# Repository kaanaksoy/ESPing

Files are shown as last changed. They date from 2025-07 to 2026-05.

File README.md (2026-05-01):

# ESPing – A Wi-Fi Button That Sleeps

**ESPing** is a battery-friendly ESP32-C6 project that acts as a stateless smart button.  
On wake, it connects to Wi-Fi, fires an MQTT event, and goes straight back to deep sleep — typically in under a second on subsequent presses.

---

## ✨ Features

- Fast wake → Wi-Fi → MQTT → sleep (~400–800 ms after the first connect)
- WiFi fast-reconnect via cached BSSID/channel/IP in RTC memory (no router config needed)
- Ultra-low-power operation (ideal for 18650 battery)
- MQTT with Home Assistant auto-discovery — appears as a native HA device with button triggers, battery sensor, and config switch
- `pressed` / `released` device-trigger events, with `retain=false` so HA doesn't replay stale presses on reconnect
- Last Will & Testament so HA correctly marks the device offline if it dies mid-session
- `preventSleep` mode for OTA flashing and live config tweaks
- Color-configurable status NeoPixel (settable from HA via MQTT)
- Battery percentage reported on every press
- **Per-board unique ID derived from chip MAC** — flash the same firmware to every unit, no per-device editing

---

## 📦 MQTT Topics

All topics are prefixed with the runtime device ID, e.g. `esping-a1b2c3d4e5f6/`.

| Topic | Direction | Description |
|---|---|---|
| `<id>/button` | publish | `pressed` then `released` on each wake (not retained) |
| `<id>/battery` | publish | JSON `{"batteryPercentage": 87.4}` (retained) |
| `<id>/state` | publish | JSON state: `preventSleep`, color, brightness (retained) |
| `<id>/availability` | publish | `online` / `offline` via LWT (retained) |
| `<id>/command` | subscribe | JSON commands — see below |
| `homeassistant/+/<id>_*/config`| publish | HA discovery payloads (retained, version-gated) |

### Command payloads

Send JSON to `<id>/command`:

```json
{"preventSleep": true}                           // stay awake (e.g. for OTA)
{"color": {"r": 255, "g": 0, "b": 128}}          // set status LED color
{"brightness": 128}                              // 0–255
{"resetDiscovery": true}                         // wipe prefs and restart
```

Color and brightness are persisted to flash and survive deep sleep.

---

## 🚀 How It Works

1. Button press wakes the ESP32 from deep sleep via EXT1 wakeup.
2. WiFi attempts a fast reconnect using cached BSSID/channel/IP from RTC memory. Falls back to a full scan + DHCP if that fails, then re-caches.
3. MQTT connects with Last Will configured.
4. `pressed` is published immediately — this is the critical path.
5. Availability, discovery (if version changed), LED fade, battery read, and `released` event follow.
6. Briefly listens for `preventSleep` or other commands, then deep-sleeps.

If `preventSleep` is set, the device stays awake in `loop()` until the flag is cleared.

---

## 🔧 Setup

### Requirements

- ESP32-C6 board (developed on the DFRobot Beetle ESP32-C6 V1.0)
- LiPo or 18650 battery (optional for portable use)
- MQTT broker (e.g. Mosquitto, including the Home Assistant Mosquitto add-on)
- Home Assistant with the MQTT integration enabled (optional but recommended)

### Configuration

Copy `credentials_example.h` to `credentials.h` and edit:

```cpp
#define WIFI_SSID     "YourWiFi"
#define WIFI_PASSWORD "YourPassword"
#define MQTT_SERVER   "192.168.1.100"
#define MQTT_PORT     1883
#define MQTT_USER     "username"
#define MQTT_PASSWORD "password"
```

Optionally tweak `defines.h`:

- `DEVICE_PREFIX` — the short tag in topics and IDs (default `esping`)
- `DEVICE_PREFIX_FRIENDLY` — the human-readable name shown in HA (default `ESPing`)
- `SW_VERSION` — bump to force HA discovery to re-publish
- `VOLTAGE_CALIBRATION_FACTOR` — per-board ADC tuning for battery readings
- `WIFI_TIMEOUT_FAST` / `WIFI_TIMEOUT_FULL` — connect timeouts

### Building multiple units

Flash the same firmware to every board. Each device derives its ID from the chip's factory MAC, so there are no client ID collisions or topic clashes. Boards appear in HA automatically with names like `ESPing a1b2c3d4e5f6` — rename them in the HA UI as you please.

### Pin assignments (Beetle ESP32-C6)

| Function | GPIO  |
|---|---|
| Button (wake) | 4 |
| NeoPixel data | 21 |
| Battery ADC | 0 |
| Built-in LED | 15 |

---

## 🔄 Upgrading from earlier versions

If you previously ran ESPing with hardcoded `DEVICE_ID` (e.g. `esping01-2`), boards will appear as new devices in HA after flashing 0.4.0+. Clean up old retained discovery topics with MQTT Explorer or `mosquitto_pub -r -n` against `homeassistant/+/<old_id>_*/config` to remove the ghost devices.

---

## 🧰 Parts List

The 3D-printed enclosure is sized specifically for these parts. Substitutions may not fit.

| Part | Notes |
|---|---|
| DFRobot Beetle ESP32-C6 | V1.0 or V1.1, both work |
| 102040 LiPo cell, 3.7 V | ~600 mAh, fits the battery pocket exactly |
| 12×12 mm tactile pushbutton  | 4-pin PCB-mount through-hole, ~7 mm body height |
| Pulldown resistor | 220 kΩ – 1 MΩ (higher = lower quiescent current on battery) |

> **Note:** Earlier revisions used a WS2812 NeoPixel on GPIO21 for press feedback. The original part is no longer available, so the LED has been omitted from the hardware and the enclosure redesigned to match. The firmware still drives GPIO21 — this is harmless when nothing is connected — and the LED color/brightness controls remain in Home Assistant for backwards compatibility.

### Wiring summary

- Button: one side to **GPIO4**, other side to **3.3 V**. Pulldown resistor from GPIO4 to **GND** (keeps the line low when the button is open so EXT1 wake fires on press).
- Battery: into the Beetle's onboard LiPo connector — the board handles charging and 3.3 V regulation.

---

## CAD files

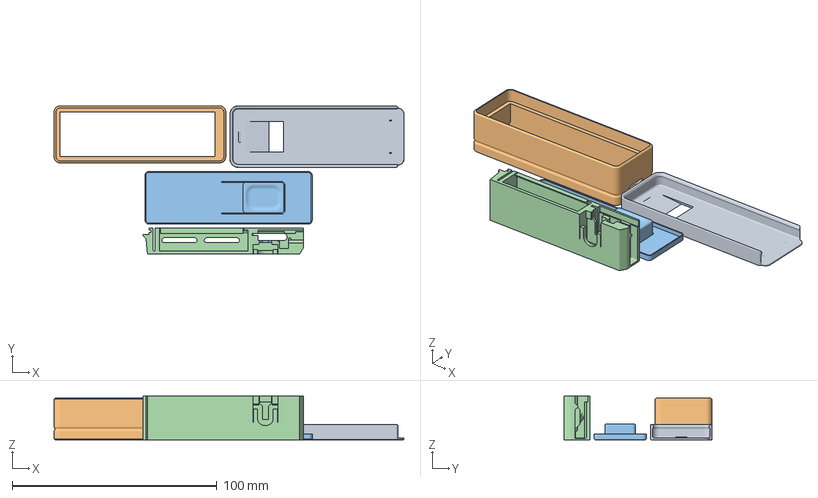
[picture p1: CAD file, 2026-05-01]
3MF/ESPing.3mf
171.1 x 72.5 x 21.4 mm
ESPing_Clip.step
ESPing_Shell.step
ESPing_Faceplate_Carrier.step
ESPing_Internal_Frame.step

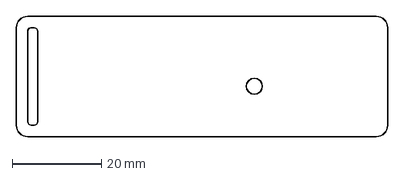
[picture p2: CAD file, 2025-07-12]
Cut Files/Bottom Cut File.dxf
83.0 x 26.9 mm

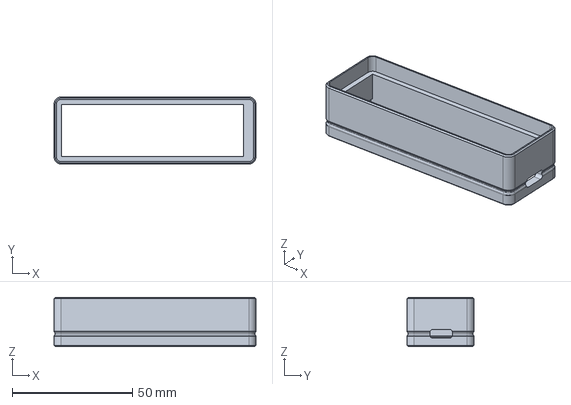
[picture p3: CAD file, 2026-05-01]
STEP/ESPing_Shell.step
84.0 x 27.9 x 20.4 mm

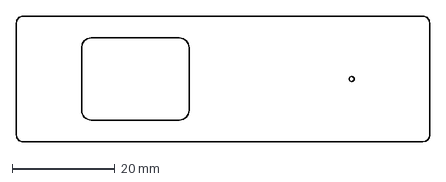
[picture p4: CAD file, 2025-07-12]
Cut Files/Top Cut File.dxf
80.6 x 24.5 mm

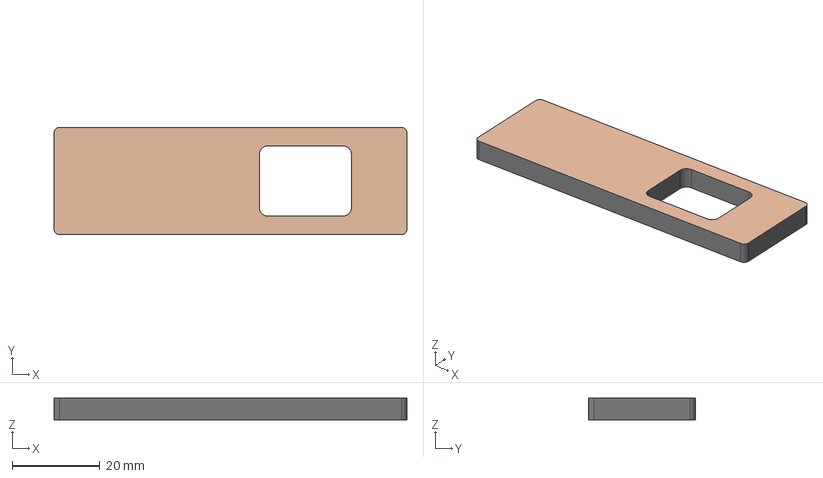
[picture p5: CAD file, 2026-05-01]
STEP/ESPing_Faceplate.step
80.6 x 24.5 x 5.00 mm

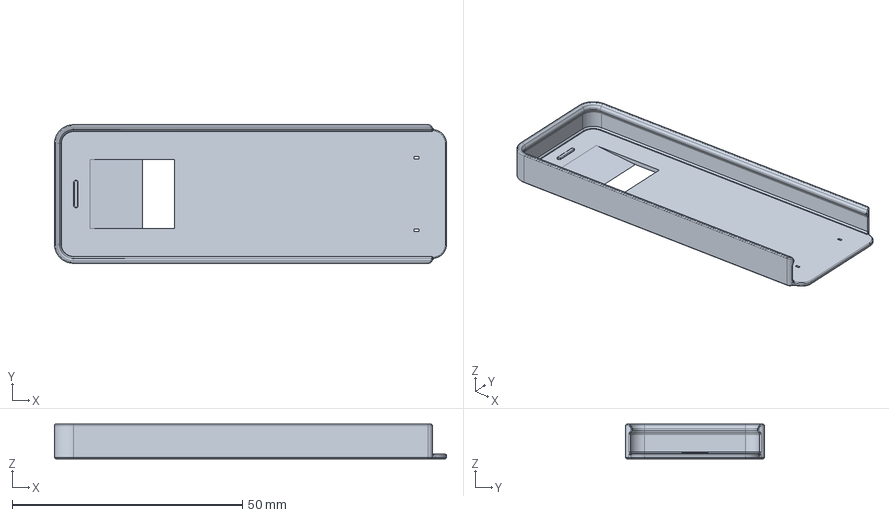
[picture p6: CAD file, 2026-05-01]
STEP/ESPing_Clip.step
85.1 x 30.1 x 7.54 mm

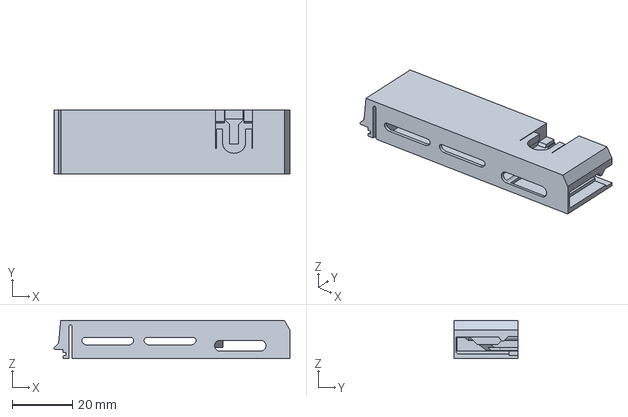
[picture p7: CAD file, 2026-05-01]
STEP/ESPing_Internal_Frame.step
78.5 x 21.4 x 12.7 mm

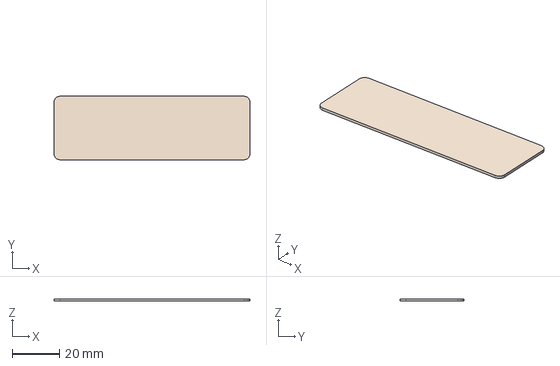
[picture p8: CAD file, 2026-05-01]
STEP/ESPing_Bottom_Liner.step
83.0 x 26.9 x 1.00 mm

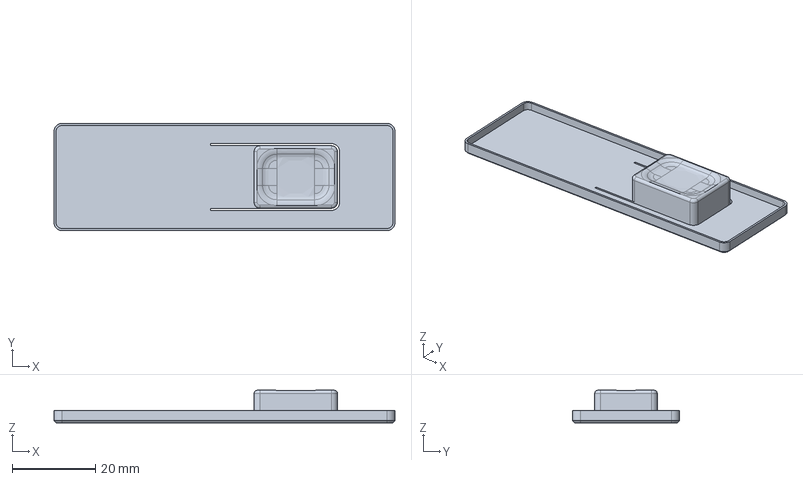
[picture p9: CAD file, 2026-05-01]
STEP/ESPing_Faceplate_Carrier.step
81.8 x 25.7 x 7.80 mm

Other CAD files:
DXF/ESPing_Faceplate.dxf
Fusion/ESPing_Assembled.f3z
STL/ESPing_Bottom_Liner.stl
STL/ESPing_Clip.stl
STL/ESPing_Faceplate.stl
STL/ESPing_Faceplate_Carrier.stl
STL/ESPing_Internal_Frame.stl
STL/ESPing_Shell.stl

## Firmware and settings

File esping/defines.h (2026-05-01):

#ifndef DEFINES_H
#define DEFINES_H

// User Configurable Settings
// DEVICE_ID is now derived at runtime from the chip's MAC (see device_id.cpp).
// DEVICE_PREFIX is the short tag used in topics:  esping-a1b2c3d4e5f6
// DEVICE_PREFIX_FRIENDLY is the human-readable prefix shown in HA.
#define DEVICE_PREFIX "esping"
#define DEVICE_PREFIX_FRIENDLY "ESPing"
#define DISCOVERY_ENABLED // Comment out to disable MQTT discovery
// #define BUILT_IN_LED_ENABLED // Enable this to use the built-in LED on the
// Beetle ESP32-C6 V1.0

// Basic Pin Definitions
#define BUTTON_PIN GPIO_NUM_4
#define BUILTIN_LED_PIN GPIO_NUM_15
#define BUTTON_PIN_BITMASK(GPIO) (1ULL << GPIO) // 2 ^ GPIO_NUMBER in hex

// MQTT Configuration
// MQTT_CLIENT_ID, topics, etc. are now built at runtime — see device_id.h
#define DISCOVERY_PREFIX                                                       \
  "homeassistant"          // Make sure this matches your HASS MQTT config
#define SW_VERSION "0.4.1" // Software version for discovery
#define HW_VERSION "0.2"   // Hardware version for discovery

// Timing — tuned for snappy + reliable press events
#define WIFI_TIMEOUT_FAST 2500 // Fast-reconnect attempt (cached BSSID/channel)
#define WIFI_TIMEOUT_FULL 8000 // Full connect fallback (scan + DHCP)
#define MQTT_CONNECT_TIMEOUT 3000 // Bounded MQTT connect (was unbounded — bug)
#define MQTT_RECONNECT_TIMEOUT 5000
#define MQTT_LOOP_WAIT 5000
#define BLINK_INTERVAL 500
#define PUBLISH_FLUSH_DELAY 50 // Let TCP bytes leave the NIC before sleep

// WS2812 LED strip
#define NEOPIXEL_PIN GPIO_NUM_21   // Regular GPIO
#define NUM_LEDS 1                 // Number of LEDs in the strip
#define FADE_DURATION 200          // Time in ms for the fade effect
#define DEFAULT_LED_BRIGHTNESS 255 // Max brightness of the LED strip (0-255)
#define LOOP_COLOR {0, 5, 255}     // Color for the loop indication
#define DEF_MESS_COLOR_R 33        // Default red value for the message color
#define DEF_MESS_COLOR_G 255       // Default green value for the message color
#define DEF_MESS_COLOR_B 30        // Default blue value for the message color
#define DEFAULT_MESSAGE_COLOR                                                  \
  {DEF_MESS_COLOR_R, DEF_MESS_COLOR_G, DEF_MESS_COLOR_B}                       \
  // Default color for the message indication

// Battery Monitoring
#define BATT_ADC_PIN                                                           \
  0 // ADC pin for the battery monitoring (For the Beetle ESP32-C6 V1.0 it's
    // GPIO 0)
#define VOLTAGE_CALIBRATION_FACTOR                                             \
  1.0186 // Calibration factor for the battery voltage (differentiates between
         // microcontrollers). For a fleet, consider per-unit calibration
         // stored in Preferences instead.
#define uS_TO_S_FACTOR                                                         \
  1000000ULL /* Conversion factor for micro seconds to seconds */

// #define SERIAL_DEBUG_ENABLED // Enable this to use the serial debug output
// DEBUGGING
#endif

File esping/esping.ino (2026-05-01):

#include "esp_wifi.h"
#include <Adafruit_NeoPixel.h>
#include <ArduinoJson.h>
#include <Preferences.h>
#include <PubSubClient.h>
#include <WiFi.h>

#include "defines.h"
#include "device_id.h"
#include "discovery.h"
#include "driver/rtc_io.h"

#if __has_include("credentials.h")
#include "credentials.h"
#else
#include "credentials_example.h"
#endif

WiFiClient wifiClient;
PubSubClient mqttClient(wifiClient);
Adafruit_NeoPixel statusLed(1, NEOPIXEL_PIN, NEO_GRB + NEO_KHZ800);
Preferences prefs;

// --- RTC memory: survives deep sleep, lost on power cycle / reset.
// We cache enough to skip the WiFi scan and DHCP on subsequent wakes.
RTC_DATA_ATTR struct {
  bool valid;
  uint8_t bssid[6];
  uint8_t channel;
  uint32_t local_ip;
  uint32_t gateway;
  uint32_t subnet;
  uint32_t dns;
} rtcWifi;

struct Color {
  uint8_t r, g, b;
};

Color messageColor = DEFAULT_MESSAGE_COLOR;
uint8_t messageBrightness = DEFAULT_LED_BRIGHTNESS;

bool preventSleep = false;
unsigned long lastBlink = 0;

// Function prototypes
void mqttCallback(char *topic, byte *payload, unsigned int length);
#ifdef SERIAL_DEBUG_ENABLED
void print_wakeup_reason();
#endif
void indicate_with_fade(Color color);
void write_led_color(Color color, int brightness);
void goToSleep();
void turn_off_led();
void loadSavedValues();
void saveNewValues(Color messageColor, uint8_t messageBrightness);
bool connectWifiFast();
bool connectWifiFull();
void cacheWifiState();
bool connectMqtt(unsigned long timeout_ms);
void publishState();
void checkAndPublishBattery();

// --- Program Begin
void setup() {
#ifdef SERIAL_DEBUG_ENABLED
  Serial.begin(115200);
  delay(1000);
  print_wakeup_reason();
  Serial.println("Booting ESPing...");
#endif

  // Build DEVICE_ID and topic strings from the chip's MAC. Must run before
  // anything that touches a topic.
  initDeviceId();

#ifdef SERIAL_DEBUG_ENABLED
  Serial.print("Device ID: ");
  Serial.println(DEVICE_ID);
#endif

#ifdef BUILT_IN_LED_ENABLED
  pinMode(BUILTIN_LED_PIN, OUTPUT);
  digitalWrite(BUILTIN_LED_PIN, HIGH);
#endif

  // ---- WiFi: try fast reconnect first, fall back to full scan ----
  bool wifiUp = false;
  if (rtcWifi.valid) {
    wifiUp = connectWifiFast();
#ifdef SERIAL_DEBUG_ENABLED
    Serial.printf("Fast reconnect: %s (%lu ms)\n", wifiUp ? "OK" : "FAIL",
                  millis());
#endif
  }
  if (!wifiUp) {
    wifiUp = connectWifiFull();
#ifdef SERIAL_DEBUG_ENABLED
    Serial.printf("Full connect: %s (%lu ms)\n", wifiUp ? "OK" : "FAIL",
                  millis());
#endif
    if (wifiUp)
      cacheWifiState();
  }
  if (!wifiUp) {
    rtcWifi.valid = false;
    goToSleep();
  }

  // ---- MQTT ----
  mqttClient.setServer(MQTT_SERVER, MQTT_PORT);
  mqttClient.setKeepAlive(10);
  mqttClient.setBufferSize(1024);
  mqttClient.setCallback(mqttCallback);

  statusLed.begin();
  statusLed.clear();
  statusLed.show();

  if (!connectMqtt(MQTT_CONNECT_TIMEOUT)) {
#ifdef SERIAL_DEBUG_ENABLED
    Serial.println("MQTT connect failed, sleeping");
#endif
    goToSleep();
  }

  // ---- Publish the press IMMEDIATELY — this is the critical path ----
  mqttClient.publish(BUTTON_TOPIC.c_str(), "pressed", /*retain=*/false);
  mqttClient.loop();

  mqttClient.publish(AVAILABILITY_TOPIC.c_str(), "online", /*retain=*/true);
  mqttClient.subscribe(COMMAND_TOPIC.c_str(), 1);

#ifdef DISCOVERY_ENABLED
  checkAndSendDiscovery();
#endif
  loadSavedValues();
  indicate_with_fade(messageColor);
  checkAndPublishBattery();

  delay(50);
  mqttClient.publish(BUTTON_TOPIC.c_str(), "released", /*retain=*/false);
  mqttClient.loop();

  unsigned long start = millis();
  while (!preventSleep && millis() - start < MQTT_LOOP_WAIT) {
    mqttClient.loop();
    delay(25);
  }
  if (!preventSleep) {
    goToSleep();
  }
}

void loop() {
  if (!preventSleep) {
    goToSleep();
  }

  if (WiFi.status() != WL_CONNECTED) {
    WiFi.reconnect();
    unsigned long t0 = millis();
    while (WiFi.status() != WL_CONNECTED && millis() - t0 < WIFI_TIMEOUT_FULL) {
      delay(50);
    }
    if (WiFi.status() != WL_CONNECTED) {
      goToSleep();
    }
  }

  if (!mqttClient.connected()) {
    if (!connectMqtt(MQTT_RECONNECT_TIMEOUT)) {
      goToSleep();
    }
  }

  mqttClient.loop();

  if (millis() - lastBlink >= BLINK_INTERVAL) {
    lastBlink = millis();
#ifdef BUILT_IN_LED_ENABLED
    digitalWrite(BUILTIN_LED_PIN, !digitalRead(BUILTIN_LED_PIN));
#endif
    indicate_with_fade(LOOP_COLOR);
  }
}

// --- Program End

// ---- WiFi helpers ----

bool connectWifiFast() {
  WiFi.mode(WIFI_STA);
  IPAddress ip(rtcWifi.local_ip);
  IPAddress gw(rtcWifi.gateway);
  IPAddress sn(rtcWifi.subnet);
  IPAddress dns(rtcWifi.dns);
  WiFi.config(ip, gw, sn, dns);
  WiFi.begin(WIFI_SSID, WIFI_PASSWORD, rtcWifi.channel, rtcWifi.bssid);

  unsigned long t0 = millis();
  while (WiFi.status() != WL_CONNECTED && millis() - t0 < WIFI_TIMEOUT_FAST) {
    delay(5);
  }
  return WiFi.status() == WL_CONNECTED;
}

bool connectWifiFull() {
  WiFi.disconnect(true, true);
  WiFi.mode(WIFI_STA);
  WiFi.config(IPAddress((uint32_t)0), IPAddress((uint32_t)0),
              IPAddress((uint32_t)0), IPAddress((uint32_t)0));
  WiFi.begin(WIFI_SSID, WIFI_PASSWORD);

  unsigned long t0 = millis();
  while (WiFi.status() != WL_CONNECTED && millis() - t0 < WIFI_TIMEOUT_FULL) {
    delay(5);
  }
  return WiFi.status() == WL_CONNECTED;
}

void cacheWifiState() {
  uint8_t *bssid = WiFi.BSSID();
  if (bssid) {
    memcpy(rtcWifi.bssid, bssid, 6);
  }
  rtcWifi.channel = WiFi.channel();
  rtcWifi.local_ip = (uint32_t)WiFi.localIP();
  rtcWifi.gateway = (uint32_t)WiFi.gatewayIP();
  rtcWifi.subnet = (uint32_t)WiFi.subnetMask();
  rtcWifi.dns = (uint32_t)WiFi.dnsIP();
  rtcWifi.valid = true;
}

// ---- MQTT helper ----

bool connectMqtt(unsigned long timeout_ms) {
  unsigned long t0 = millis();
  while (!mqttClient.connected() && millis() - t0 < timeout_ms) {
    if (mqttClient.connect(DEVICE_ID.c_str(), MQTT_USER, MQTT_PASSWORD,
                           AVAILABILITY_TOPIC.c_str(), 1, true, "offline")) {
      return true;
    }
    delay(50);
  }
  return mqttClient.connected();
}

void mqttCallback(char *topic, byte *payload, unsigned int length) {
  bool updated = false;
  StaticJsonDocument<256> doc;
  DeserializationError error = deserializeJson(doc, payload, length);
  if (error)
    return;

  if (doc.containsKey("resetDiscovery") && doc["resetDiscovery"] == true) {
    handleResetDiscovery();
    return;
  }

  if (doc.containsKey("preventSleep")) {
    preventSleep = doc["preventSleep"];
    updated = true;
  }

  if (doc.containsKey("color")) {
    JsonObject colorObj = doc["color"].as<JsonObject>();
    if (colorObj.containsKey("r"))
      messageColor.r = colorObj["r"].as<uint8_t>();
    if (colorObj.containsKey("g"))
      messageColor.g = colorObj["g"].as<uint8_t>();
    if (colorObj.containsKey("b"))
      messageColor.b = colorObj["b"].as<uint8_t>();
    updated = true;
  }

  if (doc.containsKey("brightness")) {
    int b = doc["brightness"].as<int>();
    messageBrightness = constrain(b, 0, 255);
    updated = true;
  }

  if (updated) {
    saveNewValues(messageColor, messageBrightness);
    write_led_color(messageColor, messageBrightness);
    indicate_with_fade(messageColor);
    publishState();
  }
}

float checkBatteryLevel() {
  float voltage = analogReadMilliVolts(BATT_ADC_PIN) * 2.0 *
                  VOLTAGE_CALIBRATION_FACTOR / 1000.0;
  float percentage = (voltage - 3.0) * 100.0 / (4.2 - 3.0);
  return constrain(percentage, 0, 100);
}

void write_led_color(Color color, int brightness) {
  float factor = brightness / 255.0;
  statusLed.setPixelColor(0, color.r * factor, color.g * factor,
                          color.b * factor);
  statusLed.show();
}

#ifdef SERIAL_DEBUG_ENABLED
void print_wakeup_reason() {
  esp_sleep_wakeup_cause_t wakeup_reason = esp_sleep_get_wakeup_cause();

  switch (wakeup_reason) {
  case ESP_SLEEP_WAKEUP_EXT0:
    Serial.println("Wakeup: EXT0");
    break;
  case ESP_SLEEP_WAKEUP_EXT1:
    Serial.println("Wakeup: EXT1");
    break;
  case ESP_SLEEP_WAKEUP_TIMER:
    Serial.println("Wakeup: timer");
    break;
  case ESP_SLEEP_WAKEUP_TOUCHPAD:
    Serial.println("Wakeup: touch");
    break;
  case ESP_SLEEP_WAKEUP_ULP:
    Serial.println("Wakeup: ULP");
    break;
  default:
    Serial.printf("Wakeup: not deep sleep (%d)\n", wakeup_reason);
    break;
  }
}
#endif

void indicate_with_fade(Color color) {
  unsigned long startTime = millis();
  while (millis() - startTime < FADE_DURATION) {
    float progress = (float)(millis() - startTime) / FADE_DURATION;
    float brightness = sin(progress * PI) * messageBrightness;
    brightness = constrain(brightness, 0, messageBrightness);
    write_led_color(color, brightness);
    delay(1);
  }
  statusLed.clear();
  statusLed.show();
}

void turn_off_led() {
  statusLed.clear();
  statusLed.show();
  pinMode(NEOPIXEL_PIN, OUTPUT);
  digitalWrite(NEOPIXEL_PIN, LOW);
}

void goToSleep() {
  turn_off_led();
  esp_sleep_enable_ext1_wakeup(BUTTON_PIN_BITMASK(BUTTON_PIN),
                               ESP_EXT1_WAKEUP_ANY_HIGH);

  if (mqttClient.connected()) {
    mqttClient.publish(AVAILABILITY_TOPIC.c_str(), "offline", /*retain=*/true);
    mqttClient.loop();
    delay(PUBLISH_FLUSH_DELAY);
    mqttClient.disconnect();
  }
  WiFi.disconnect(true, true);
  WiFi.mode(WIFI_OFF);
  esp_wifi_stop();

#ifdef BUILT_IN_LED_ENABLED
  digitalWrite(BUILTIN_LED_PIN, LOW);
#endif

  esp_deep_sleep_start();
}

void loadSavedValues() {
  prefs.begin("esping", false);
  messageBrightness = prefs.getUChar("brightness", DEFAULT_LED_BRIGHTNESS);
  messageColor.r = prefs.getUChar("r", DEF_MESS_COLOR_R);
  messageColor.g = prefs.getUChar("g", DEF_MESS_COLOR_G);
  messageColor.b = prefs.getUChar("b", DEF_MESS_COLOR_B);
  prefs.end();
}

void saveNewValues(Color messageColor, uint8_t messageBrightness) {
  prefs.begin("esping", false);
  prefs.putUChar("brightness", messageBrightness);
  prefs.putUChar("r", messageColor.r);
  prefs.putUChar("g", messageColor.g);
  prefs.putUChar("b", messageColor.b);
  prefs.end();
}

void publishState() {
  StaticJsonDocument<256> doc;
  doc["preventSleep"] = preventSleep;
  JsonObject colorObj = doc.createNestedObject("color");
  colorObj["r"] = messageColor.r;
  colorObj["g"] = messageColor.g;
  colorObj["b"] = messageColor.b;
  doc["brightness"] = messageBrightness;
  doc["resetDiscovery"] = false;

  String payload;
  serializeJson(doc, payload);
  mqttClient.publish(STATE_TOPIC.c_str(), payload.c_str(), true);
}

void checkAndPublishBattery() {
  pinMode(BATT_ADC_PIN, INPUT);
  float batteryLevel = checkBatteryLevel();
  StaticJsonDocument<64> doc;
  doc["batteryPercentage"] = (int)round(batteryLevel);
  String payload;
  serializeJson(doc, payload);
  mqttClient.publish(BATTERY_TOPIC.c_str(), payload.c_str(), true);
}

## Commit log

2025-06-30 Bugfix: Server doesn't receive "Pressed" message (increased delay between the two messages).
    [esping.ino]
2025-07-12 Improvements in Progress
    [Bottom Cut File.dxf, Top Cut File.dxf]
2025-07-12 Added 3d print files
    [Button Carrier.stl, Core.stl, Faceplate.stl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]
2026-05-01 Add fast WiFi reconnect and fix button publish reliability
    Cache BSSID, channel, and DHCP-assigned IP in RTC memory to skip the
    WiFi scan and DHCP handshake on wake. Falls back to a full connect if
    the cached AP isn't reachable, then re-caches. Cuts wake-to-publish
    time from ~2-3s to ~400-800ms on subsequent presses.
    Reliability fixes:
    - Set retain=false on BUTTON_TOPIC; retained press events were causing
    spurious HA triggers on reconnect
    - Bound the MQTT connect loop with a timeout (was unbounded — could
    spin forever if broker was unreachable)
    - Configure LWT in mqttClient.connect() so the broker marks the device
    offline if it dies mid-session
    - Publish "pressed" immediately after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
    [Slice FIle.3mf]
2026-05-01 Derive DEVICE_ID from chip MAC at runtime
    Replaces hardcoded DEVICE_ID/DEVICE_NAME and compile-time topic macros
    with runtime String globals built from ESP.getEfuseMac() in a new
    device_id module. Each board now gets a unique ID automatically —
    flashing the same firmware to multiple units no longer causes MQTT
    client ID collisions or topic clashes.
    Topics, discovery uniq_ids, and HA device.identifiers all derive from
    the runtime ID. DEVICE_PREFIX in defines.h controls the human tag.
    Bumps SW_VERSION to 0.4.0 (existing boards will appear as new devices
    in HA — clean up the old retained discovery topics on the broker).
    [defines.h, esping.ino]
2026-05-01 Added CAD Files, updated readme
    [Button Carrier.stl, Core.stl, ESPing.3mf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]
2026-05-01 Updated Assembled Model
    [ESPing_Assembled.f3z]
2026-05-01 Round battery percentage to integer
